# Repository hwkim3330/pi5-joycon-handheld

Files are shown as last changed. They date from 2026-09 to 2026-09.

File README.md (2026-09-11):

# Pi 5 + 5" Touch Display 2 + Joy-Con
## Clear Laser-Cut Acrylic Handheld

**Status: v8 SUBMITTED FOR FABRICATION — PHYSICAL FIT NOT YET VERIFIED.**
Neither the Joy-Con guide nor the display fit has been checked on real parts.
Geometry is validated against the official 5" STEP, the Cuttlephone reference and the
ordered drawing itself (`python3 verify_dxf.py`).

| front | rear (open back) |
|---|---|
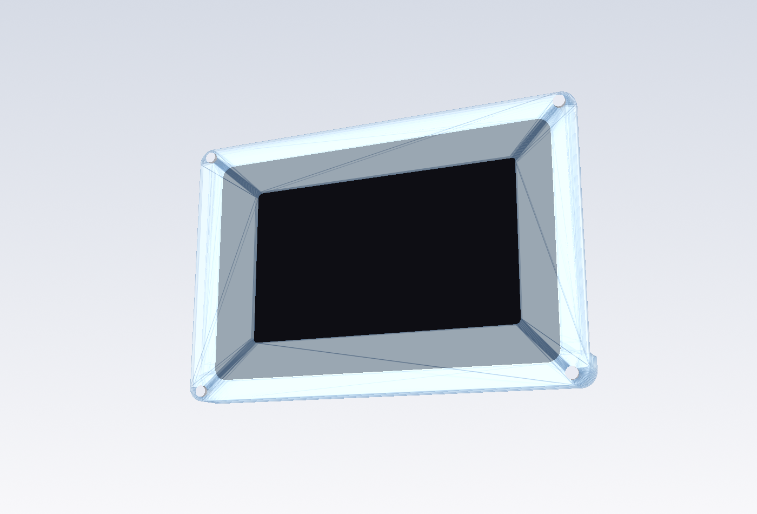
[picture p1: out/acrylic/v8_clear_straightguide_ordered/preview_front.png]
front
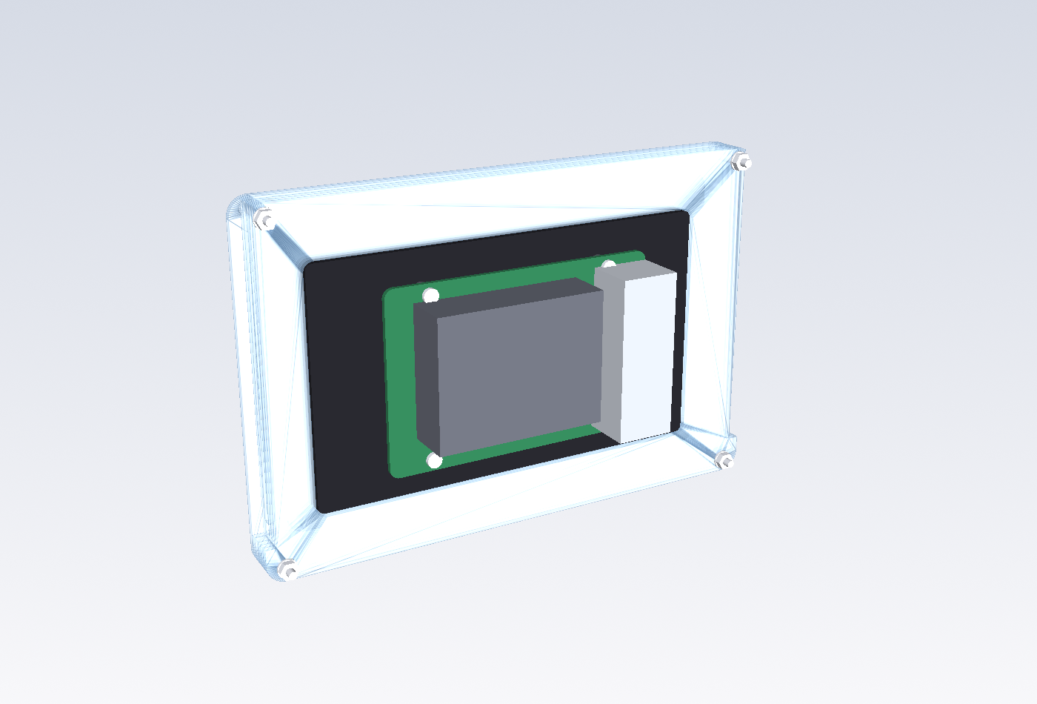
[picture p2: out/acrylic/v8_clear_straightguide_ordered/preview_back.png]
back
|  |  |

| exploded | side guide section |
|---|---|
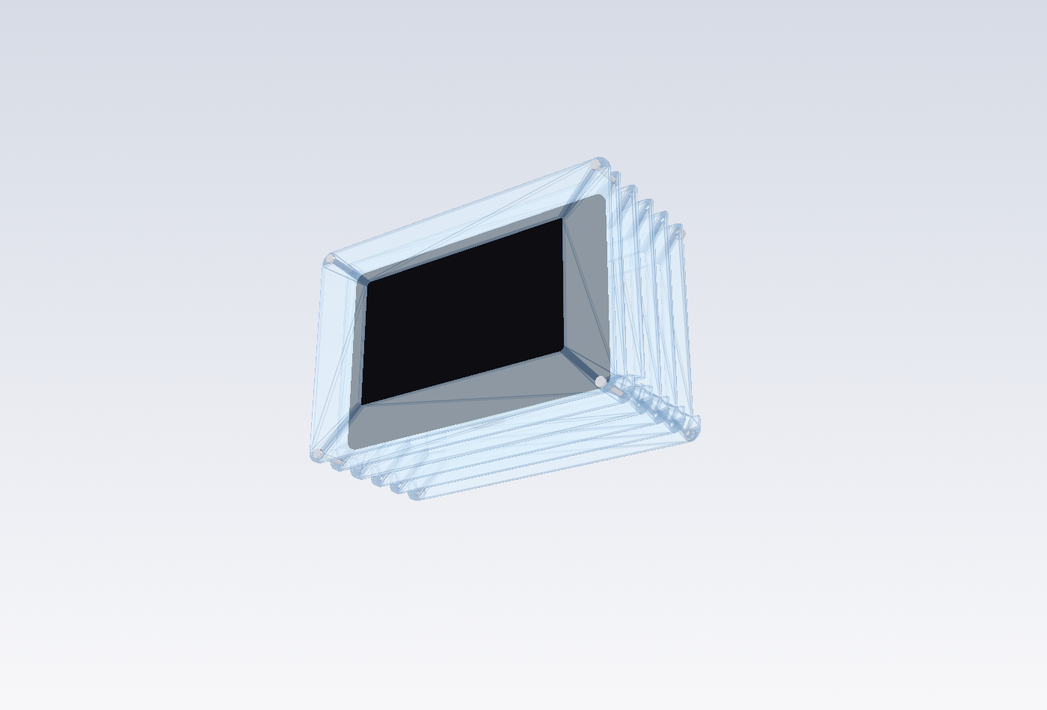
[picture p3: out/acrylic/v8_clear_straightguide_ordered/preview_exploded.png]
exploded
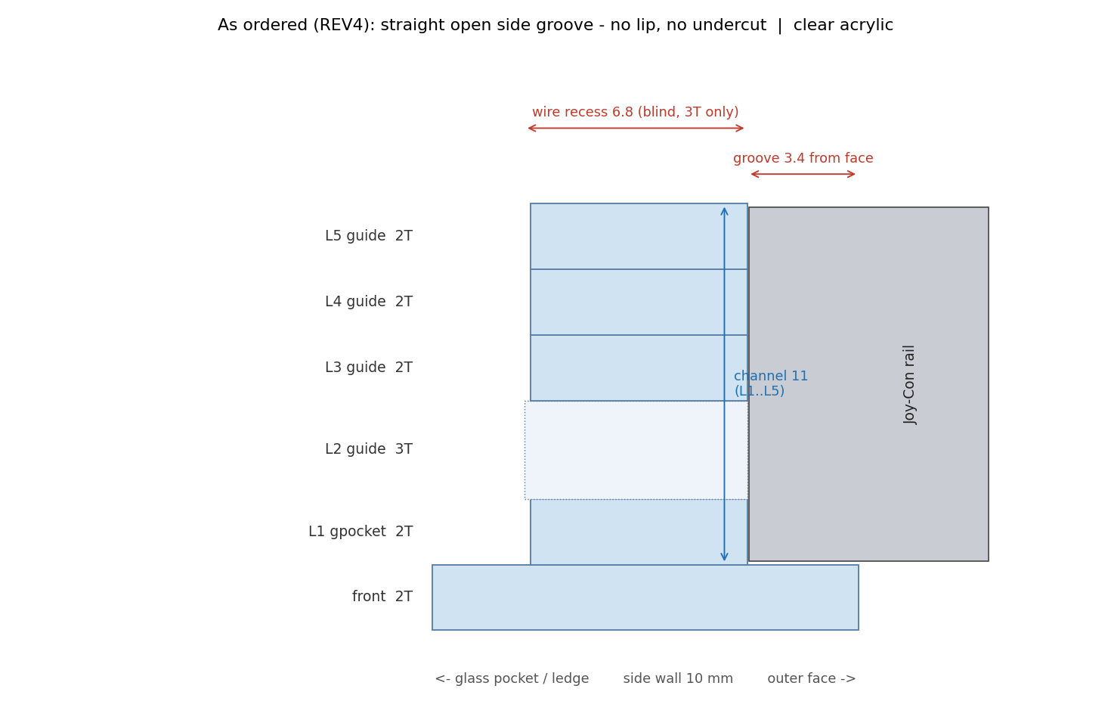
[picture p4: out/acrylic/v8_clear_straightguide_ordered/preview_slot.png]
slot
|  |  |

## What it is
A **13.0 mm** stack of **clear cast acrylic** around the official **Raspberry Pi Touch
Display 2 (5")**, open at the back so the **Raspberry Pi 5**, its Active Cooler / NVMe
HAT and cables stay visible. Real first-generation **Joy-Cons slide into straight open
grooves** cut into the side walls — no 3D printing, no glue. All case fasteners are
**silver M2.5 button-heads** on the front, washer + nut on the rear face.

Body 164.4 × 108.5 mm, 6 acrylic pieces. Source of truth for every number:
`acrylic_panels.py`; `verify_dxf.py` re-measures the exported DXFs against it *and*
against dimensions read off the ordered drawing.

**Interactive assembly guide (3D, click a plate to identify it):
https://hwkim3330.github.io/pi5-joycon-handheld/**

**Build it from [`ASSEMBLY.md`](ASSEMBLY.md); order it from [`ORDER.md`](ORDER.md).**

> **Parts fabricated.** The straight groove locates a Joy-Con but does **not** retain it:
> the mouth is 11.0 mm, the rail head is 10.1 mm, and with no undercut nothing overhangs
> it. That is the accepted cost of dropping the 1 mm lip, not a fabrication error.
> `out/acrylic/v8r_liplayers_recut/` re-cuts **only L1 and L5** with the blind lip pocket
> to restore a real T-slot (mouth 7.0), reusing the front, L2, L3 and L4 you already have.
> See ASSEMBLY.md §6.

## Versions
| version | side guide | layers | total | sheets | status |
|---|---|---|---|---|---|
| **v8_clear_straightguide_ordered** | straight groove 3.4 deep, no lip | 2 / 2 / **3** / 2 / 2 / 2 | **13.0 mm** | 2T · 3T | **ordered / fabricated** |
| v7_clear_exact | T-slot, 1.5T pockets, inner 10.0 | 2 / 1.5 / 5 / 2 / 1.5 / 1.5 | 13.5 mm | 1.5T · 2T · 5T | earlier reference |
| v7_clear_acrylzip | T-slot, 2T pockets, inner 11.0 (+PET liners) | 2 / 2 / 5 / 2 / 2 | 13.0 mm | 2T · 5T | earlier reference |

Every version has a matching fit coupon in `out/acrylic/test_coupon_<version>/`.

## Design history
1. **v7 T-slot** (`v7_clear_exact`, `v7_clear_acrylzip`) — female T-slot with a 1.0 mm
   acrylic lip, built from stacked pocket/mouth layers. Kept as reference; **not** what
   was ordered.
2. **v8 straight guide** — the ordered revision. The T-slot left a 1.0 mm lip running the
   full length of the slot on the pocket layers: laser-cuttable, but a long thin acrylic
   tongue and judged mechanically fragile. It was replaced by a plain straight groove in
   every structural layer, so the side wall keeps full section. The 5T sheet was dropped
   and its depth redistributed as 3T + one more 2T layer, holding the total at 13.0 mm.
   The cost is that a straight groove has no undercut: it guides the Joy-Con but does not
   lock it, so some lateral play is expected and accepted.
3. **Jetson Nano / Orin experiments** — a separate line of work that considered a Jetson
   as the brain instead of a Raspberry Pi. Never part of this repository's design and
   **not part of this order**. Only a stale comment in `legacy/switch_handheld.py`
   survives from it.

## As ordered (v8)
Fabricated from `KETI_Acrylic_Order_REV4_StraightGuide_Transparent_2T_3T.dxf`:
transparent acrylic, **Front 2T + L1 2T + L2 3T + L3 2T + L4 2T + L5 2T = 6 pieces,
13.0 mm**, body ≈ 164.4 × 108.5 mm, open rear, M2.5 through-bolt assembly, no acrylic glue.

* **Side guide** — straight open groove, **3.4 mm** deep, open at the top edge, **91.5 mm**
  of guide with a **6 mm** contact bay below it (97.5 mm of groove, ~11 mm of solid
  acrylic under that). Present in L1–L5; the front plate has no groove and closes the
  front of the 11 mm channel. No 1 mm tongues anywhere.
* **L2 (3T)** keeps a **3.2 × 6.8 mm wire recess** on both sides in the contact-bay
  region, for future charging contacts. As drawn it is **blind** — it stops 5.4 mm short
  of the display cavity, so feeding a wire in from the inside needs an opening that is
  not in the ordered drawing.
* Optional thin clear PET/tape may be added to the groove faces after a physical fit test.

`verify_dxf.py` checks the generated v8 DXFs against dimensions measured from that
drawing: outline, bolt pattern, window size and offset, glass pocket, ledge cavity and
offset, groove floor and bottom, wire recess, and the 2/2/3/2/2/2 thickness list.

## Assembly, front to rear
```
M2.5 button-head → front 2T → Touch Display 2 → L1 2T → L2 3T → L3 2T → L4 2T → L5 2T → washer + nut
```
The display is **not** sandwiched between two flat sheets: its 0.70 mm cover glass is
seated in the **L1 pocket** (144.40 × 92.46), and L2–L5 have a smaller frame-shaped
cavity (126.24 × 74.46, offset x −3.47) so the glass border rests on that ledge while the
rear frame passes through. Full procedure in [`ASSEMBLY.md`](ASSEMBLY.md).

## The display, measured from the official STEP
`reference/td2_5in.step` is Raspberry Pi's own 5" model (RP-009152-DD-1, public on the
Product Information Portal). Read with CadQuery; landscape here = display long axis
along case X, origin at the glass centre.

| feature | mm | in code |
|---|---|---|
| cover glass | 143.40 × 91.46 × **0.70**, corners **R5.0** | `GLASS_*` |
| rear frame (largest rear body) | 124.74 × 72.96, centre **x −3.47** from the glass centre, **9.70** behind the glass back | `FRAME_*` |
| glass + frame envelope in the STEP | **10.40** — what the acrylic pocket is sized to | `STEP_BODY_D` |
| complete product depth (documentation) | **16.0** — includes the rear stand-offs and what mounts on them | `OFFICIAL_DEPTH` |
| active-area (panel) centre | **x −2.47** from the glass centre → bezel 13.5 mm one end, 18.4 the other | `PANEL_DX` → `ACT_DX` |
| four rear M2.5-size bosses | (±51.85, ±25.5) = **103.7 × 51.0** — display assembly features, *not* Pi mounting | `STEP_REAR_BOSSES` |
| Pi mounting stand-offs | **not modelled in the STEP** | — |
| anything outside the frame footprint or behind its rear plane | none | |
| active / viewing area (product brief) | 110.4 × 62.1 / 111.5 × 63.0 | `ACTIVE_*`, `VIEW_*` |

The window is cut to the **viewing** area + 0.25 mm/side = 112.0 × 63.5, centred on the
panel (x −2.47), not on the glass. Active and viewing areas are separate variables.
Official drawings are reference-only: **measure a real display before any volume order**
(the sign of `ACT_DX` flips if you rotate the display the other way).

### How the display is held (like every bezel)
```
front 2T  ────────────────────────   clear, window over the viewing area
L1 1.5T   glass pocket 144.4 × 92.46 : the 0.70 glass sits here, gasket ring behind its border
L2…       ledge cavity 126.24 × 74.46: the glass border rests on this step (≥ 4.6 mm wide)
          the 9.7 mm rear frame passes through; open back
```
Body depth is sized to the STEP's 10.40 mm glass + frame envelope, **not** to the 16 mm
complete-product depth in the documentation — the difference is the rear stand-offs and
the Pi, which deliberately stick out of the open back.
Forward: front plate. Backward: the ledge. Nothing else is needed — the earlier
"rear retaining bars" idea was wrong: at the module's edge there is only 0.7 mm of glass,
no rear surface to press on. The **STEP-modelled glass/frame body** ends 1.1 mm (exact) / 0.6 mm (acrylzip) inside
the case back; the rear stand-offs and the Pi bolted to them project out through the
open back, which is why the complete product is documented as 16 mm deep while the
acrylic body is only 11.5.

### Pi 5 mounting
Per Raspberry Pi's documentation you can mount **any SBC form-factor Raspberry Pi
directly to the back of the Touch Display 2**: align the Pi with the **four corner
stand-offs** on the display rear and secure it with the **four supplied M2.5 screws**.
That is the method assumed here. Cables: 22→15-way FFC, display J1 → Pi GPIO power.

Those four screws hold the Pi to the display. They are **not** the case bolts and have
nothing to do with holding the display in the acrylic.

The STEP models the glass and frame body only — it does **not** model the stand-offs, so
their exact coordinates and height are not published data. The preview therefore draws
the Pi's 58 × 49 pattern centred on the display's rear frame, at a nominal 4 mm
stand-off height; treat that placement as illustration. (An earlier revision of this
repo misread the STEP's four 103.7 × 51.0 rear bosses as the Pi mounting points and
wrongly concluded a bracket was required. Those bosses are display assembly features.
No case geometry was ever derived from them.)

## Joy-Con geometry (v7 reference)
The ordered v8 replaces this T-slot with a plain groove (see *Design history*); the
reference numbers below are why the slot sits where it does, and still set the guide
length, contact bay and groove depth in v8.

Nintendo puts the **female slot on the console** and the **male rail on the Joy-Con**.
Reference geometry is derived from the field-tested
[Cuttlephone](https://github.com/SiloCityLabs/Cuttlephone) design (`phone_case.scad`):
mouth 7.1, inner 10.1, cavity 2.4, lock notch 3.8 wide 9.4 from the top, rail 91.5.
Laser kerf and actual sheet thickness still require a physical fit test.

In v7 this was built from the layer stack as a T profile (mouth 5T + 2T = 7.0, inner
7.0 + 2 × pocket, lip 1.0). **v8 drops the lip entirely** and cuts one plain 3.4 mm
groove per layer instead; what carries over is the extent — open at the top edge, Joy-Con
seated 91.5 mm below it, 6 mm contact bay under that for a Joy-Con charging-rail part
(pin 4 = 5 V, pins 1–2 = GND).

## Bezel (cosmetic, optional)
The front is clear, so the display's black bezel shows through it — that is the design.
To hide it, put black vinyl / masking film on the **back** of the front plate, leaving the
112.0 × 63.5 window open. No extra sheet.

## Kerf
DXF geometry is nominal finished geometry; the shop applies cutter compensation; do not
add your own offset. Slot widths come from sheet thickness, hence the coupon.

## Still to verify on hardware
1. **Joy-Con fit in the straight guide** — how much lateral play there actually is, and
   whether a PET/tape liner is wanted. Nothing has been tried on real parts.
2. Real glass/frame dimensions vs the STEP on your unit (reference-only drawings).
3. Stand-off positions and height on a real display (not in the STEP), and that the
   Pi + Active Cooler clear the case back as drawn.

## Files
```
acrylic_panels.py    all geometry + design checks (raises before exporting on failure)
verify_dxf.py        re-measures the exported DXFs against the code
render_previews.py   preview PNGs (VTK) + slot section (matplotlib)
ORDER.md             what to order, per version, plus hardware BOM
ASSEMBLY.md          build order and procedure for the as-ordered v8
make_site.py         builds docs/ - the GitHub Pages 3D assembly viewer
docs/                the published page (index.html + plates.json)
reference/measure_step.py  re-measures the official 5" STEP -> every display number here
reference/README.md        how to download td2_5in.step (5.2 MB, deliberately not committed)
out/acrylic/v8_clear_straightguide_ordered/  AS ORDERED - DXFs, sheet_*.dxf, manifest.txt, previews, STL
out/acrylic/v8r_liplayers_recut/   retrofit: 2 replacement plates (L1r, L5r) that add the missing undercut
out/acrylic/v7_clear_exact/        earlier T-slot reference
out/acrylic/v7_clear_acrylzip/     earlier T-slot reference, standard thicknesses
out/acrylic/test_coupon_ordered/   fit coupon for the ordered guide
out/acrylic/test_coupon_exact/     fit coupon, v7
out/acrylic/test_coupon_acrylzip/  fit coupon, v7
legacy/                            earlier drafts — NOT FOR FABRICATION
```
`pip install cadquery ezdxf`, then `python3 acrylic_panels.py && python3 verify_dxf.py && python3 render_previews.py`.

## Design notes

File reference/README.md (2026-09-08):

# reference — official Raspberry Pi 5" Touch Display 2 model

`td2_5in.step` is **not committed** (5.2 MB binary). Fetch it, then re-run the
measurement to reproduce every display number in `acrylic_panels.py`:

```bash
curl -L -o reference/td2_5in.step \
 'https://pip-assets.raspberrypi.com/categories/1083-raspberry-pi-touch-display-2/documents/RP-009152-DD-1-raspberry-pi-touch-display-2-step-5inch.step'
python3 reference/measure_step.py
```
(Product Information Portal → Raspberry Pi Touch Display 2 → *raspberry-pi-touch-display-2-step-5inch*, RP-009152-DD-1, no login.)

## Measured 2026-09-08 — what the design uses
Portrait STEP coordinates, origin as authored; **+Z is the front**.

| feature | value |
|---|---|
| cover glass | 91.46 × 143.40 × **0.70**, corner **R5.0** (8 circular edges), centre (0, +2.47) |
| rear frame (largest rear body) | 72.96 × 124.74 × 7.00, centre (0, −1.00), z[−5.48, +1.52] |
| active panel body | 71.16 × 120.94 × 2.57, centre (0, 0) |
| frame centre vs glass centre | **−3.47** along the long axis |
| panel centre vs glass centre | **−2.47** along the long axis |
| total depth (glass front → rearmost) | **10.40** (4.92 → −5.48) |
| four rear M2.5-size bosses | 4 × (±25.50, −49.38 / +54.32) → pitch **51.00 × 103.70**; boss r1.75, hole r1.25, z[−5.48, −1.98]. Display assembly, *not* Pi mounting |
| FFC connector block | 21.00 × 8.90 × 2.70 at (0.03, +37.37) |
| J1 power connector block | 16.40 × 5.20 × 2.00 at (+4.13, −30.19) |
| outside the frame footprint | none |
| behind the frame rear plane | none |

Two consequences the documentation does not spell out:

1. **The STEP models the glass + frame body only: a 10.40 mm envelope.** The
   documented depth of the complete product is **16 mm** — the difference is the rear
   mounting stand-offs and whatever is bolted to them. The acrylic pocket is sized to
   10.40; the stand-offs and the Pi pass through the open back.
2. **The stand-offs are not in the STEP.** Its four rear M2.5-size bosses are
   103.70 × 51.00 apart, which is no Pi hole pattern, so they are display assembly
   features. Per Raspberry Pi's documentation an SBC-form-factor Pi mounts directly to
   the display's four corner stand-offs with the four supplied M2.5 screws. Do not
   derive case geometry from the 103.70 × 51.00 bosses (this repo does not).

Official drawings are reference-only. Measure a real display before a volume order.

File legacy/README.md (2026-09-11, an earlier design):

# legacy — NOT FOR FABRICATION

Earlier drafts kept for reference only.

* `joycon_rail.py` — modelled a MALE dovetail on the case. Backwards: on a Switch the
  console has the female T-slot and the Joy-Con carries the male rail.
* `switch_handheld.py` — an all-3D-printed shell with the same wrong rail.

`switch_handheld.py` still carries Jetson-era comments from a separate line of
experiments (Jetson Nano / Orin Nano as the brain). Those experiments were never part of
this repository's design and were **not** part of the acrylic order — see the design
history in the main README.

The current design is `../acrylic_panels.py`.

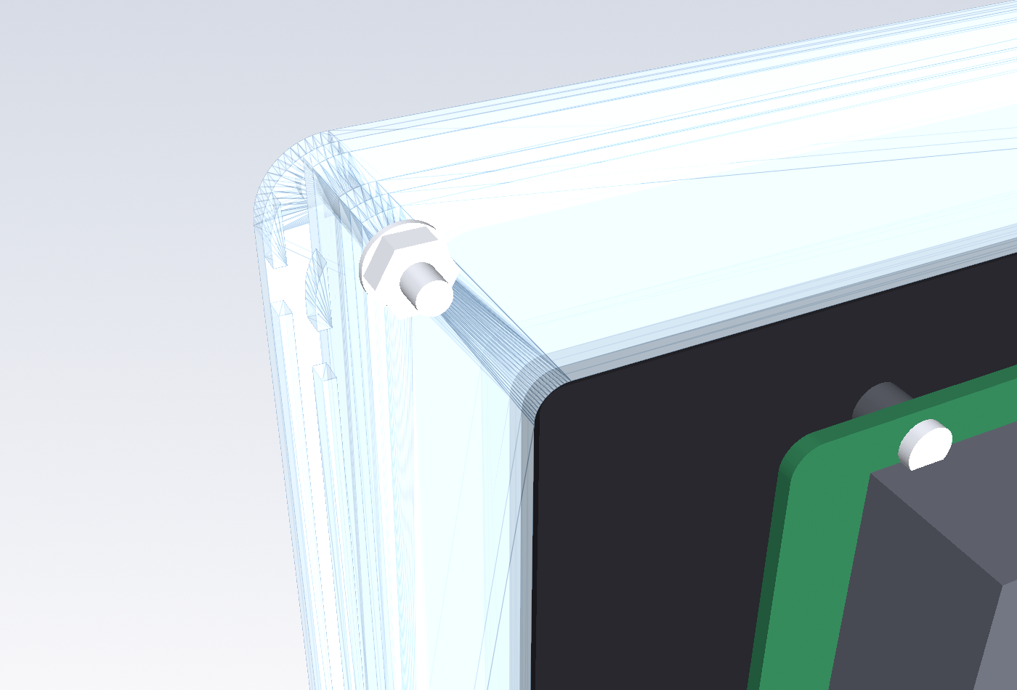
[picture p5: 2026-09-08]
out/acrylic/v7_clear_acrylzip/preview_ledge.png

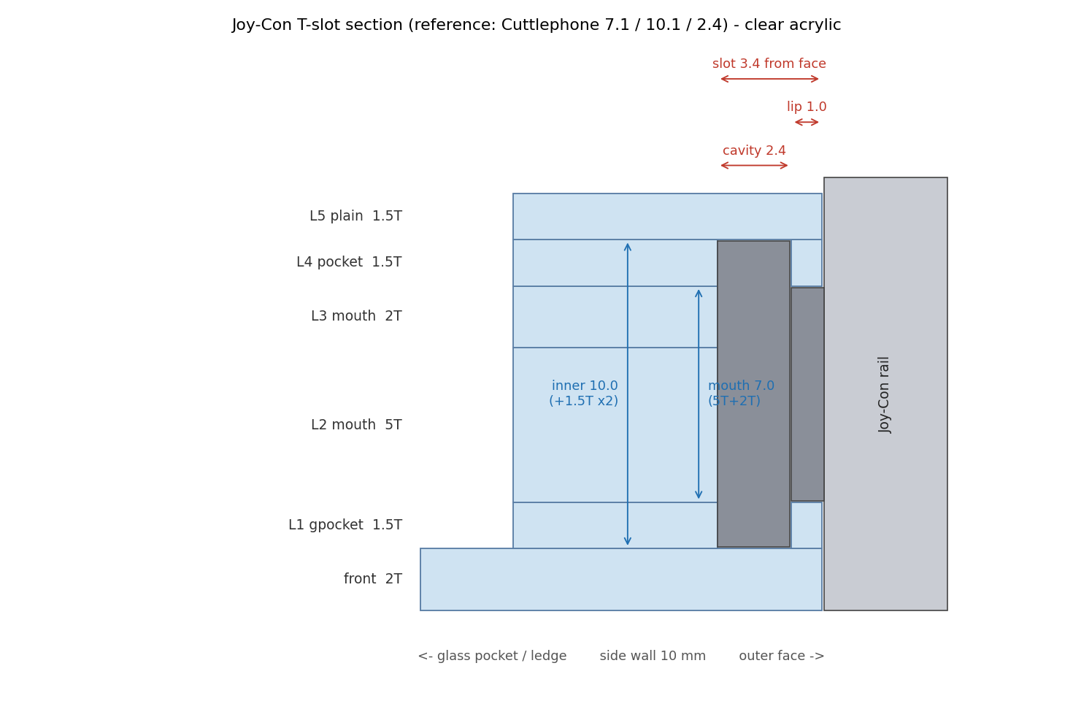
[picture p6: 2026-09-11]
out/acrylic/v7_clear_exact/preview_slot.png

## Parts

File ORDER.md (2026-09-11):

# ORDER — clear cast acrylic + silver hardware

Everything is **clear (transparent) CAST acrylic**. No black, no smoked. All case
hardware is **silver / stainless M2.5**. Hand the shop `out/acrylic/<version>/sheet_<thickness>.dxf`
— one DXF per thickness.

> **What was actually ordered is v8 (below).** v7 is kept as the earlier reference design.
>
> **Cut a fit coupon first.** Each version has one in `out/acrylic/test_coupon_<version>/`:
> a 40 mm section of the side guide with the identical layer order and geometry, two M2.5
> clamp bolts, slide a Joy-Con in from the open end. The guide has never been cut in
> acrylic — for the ordered v8 the coupon is `test_coupon_ordered` (5 pieces, 2T + 3T).

## v8_clear_straightguide_ordered — AS ORDERED / AS FABRICATED

Submitted as `KETI_Acrylic_Order_REV4_StraightGuide_Transparent_2T_3T.dxf`.
**Fabrication submitted; physical fit not yet verified.**

| part | thickness | qty | material | color | notes |
|---|---|---|---|---|---|
| front | 2T | 1 | cast acrylic | **clear** | window 112.0 × 63.5 at x −2.47; no groove |
| L1 | 2T | 1 | cast acrylic | clear | glass pocket 144.40 × 92.46; straight groove |
| L2 | **3T** | 1 | cast acrylic | clear | ledge cavity; groove; 3.2 × 6.8 blind wire recess both sides |
| L3 | 2T | 1 | cast acrylic | clear | ledge cavity; straight groove |
| L4 | 2T | 1 | cast acrylic | clear | ledge cavity; straight groove |
| L5 | 2T | 1 | cast acrylic | clear | ledge cavity; straight groove |

**6 acrylic pieces, 13.0 mm total, body 164.4 × 108.5 mm, open rear, no glue.**
Sheets: `sheet_2T.dxf` (front, L1, L3, L4, L5) and `sheet_3T.dxf` (L2).

Side guide: plain straight groove **3.4 mm** deep, open at the top edge, **91.5 mm** guide
+ **6 mm** contact bay. No T-lip. Lateral play is accepted; thin clear PET/tape may be
added after a fit test.

Hardware: **4 × M2.5 × 18** silver button-head (17.0 mm needed; ×20 with nyloc),
4 × M2.5 washer, 4 × M2.5 nut. Plus the gasket strip listed in the BOM below.

> The same fabrication sheet also carried a separate project — 20 × LAN9692 frame plates
> (A/B/C/D, 3T, 5 each, 250 × 180 mm). Nothing to do with this case.

## The two earlier v7 reference versions
| | v7_clear_exact | v7_clear_acrylzip |
|---|---|---|
| Joy-Con pocket layers (L1, L4) | **1.5T** | **2T** |
| raw Joy-Con inner width | 10.0 mm (reference 10.1) | 11.0 mm |
| liners | none | 0.45 mm clear PET on each pocket face → ~10.1 |
| body / total acrylic thickness | 11.5 / **13.5 mm** | 11.0 / **13.0 mm** |
| sheets | 1.5T · 2T · 5T | 2T · 5T |
| use when | the shop can supply 1.5T clear cast | standard-thickness auto-quote (Acrylzip 아크리애) |

These were the T-slot designs that preceded the ordered revision. If 1.5T clear cast is available, **exact** is the closer of the two to the reference geometry. The acrylzip version is the
standard-thickness fallback; its 11.0 mm inner width is not "close enough" on its
own — fit the liners.

## v7_clear_exact — parts (6 acrylic pieces)
| part | thickness | qty | material | color | notes |
|---|---|---|---|---|---|
| front | 2T | 1 | cast acrylic | clear | window 112.0 × 63.5 at x −2.47 (viewing area + 0.25/side), 4 × Ø2.8 |
| L1_gpocket | **1.5T** | 1 | cast acrylic | clear | glass pocket 144.40 × 92.46 R5.5 **+** Joy-Con slot pocket + lock notch |
| L2_mouth | 5T | 1 | cast acrylic | clear | frame-size ledge cavity 126.24 × 74.46 (x −3.47) + slot mouth + 3.2 wire slot |
| L3_mouth | 2T | 1 | cast acrylic | clear | ledge cavity + slot mouth |
| L4_pocket | **1.5T** | 1 | cast acrylic | clear | ledge cavity + slot pocket + lock notch |
| L5_plain | 1.5T | 1 | cast acrylic | clear | ledge cavity; the STEP glass/frame body ends 1.1 mm inside the case back |

Sheets: `sheet_1.5T.dxf` (L1, L4, L5), `sheet_2T.dxf` (front, L3), `sheet_5T.dxf` (L2).

## v7_clear_acrylzip — parts (5 acrylic pieces)
| part | thickness | qty | material | color | notes |
|---|---|---|---|---|---|
| front | 2T | 1 | cast acrylic | clear | as above |
| L1_gpocket | **2T** | 1 | cast acrylic | clear | glass pocket + slot pocket; liner on the slot face |
| L2_mouth | 5T | 1 | cast acrylic | clear | ledge + mouth + wire slot |
| L3_mouth | 2T | 1 | cast acrylic | clear | ledge + mouth |
| L4_pocket | **2T** | 1 | cast acrylic | clear | ledge + slot pocket; liner on the slot face. STEP glass/frame body ends 0.6 mm inside |

Sheets: `sheet_2T.dxf` (front, L1, L3, L4), `sheet_5T.dxf` (L2).

## Fit coupons (cut these first)
| folder | pieces | thicknesses |
|---|---|---|
| **`test_coupon_ordered`** | **5** — C1 2T, C2 3T, C3 2T, C4 2T, C5 2T | **2T, 3T** (matches the ordered build) |
| `test_coupon_exact` | **5** — C1 1.5T, C2 5T, C3 2T, C4 1.5T, C5 1.5T | 1.5T, 2T, 5T |
| `test_coupon_acrylzip` | **4** — C1 2T, C2 5T, C3 2T, C4 2T | 2T, 5T |

16 × 40 mm each, slot open at the top, 6 mm stop at the bottom, two Ø2.8 clamp holes.
Clamp with 2 × M2.5 × 20 + nuts.

## Hardware BOM (case) — separate from the display's own screws
| item | qty | spec | note |
|---|---|---|---|
| button-head screw | 4 | **M2.5 × 18**, silver / A2 stainless | computed: v8/acrylzip stack 13.0 + washer 0.5 + nut 2.0 + 1.5 stick-out = 17.0 → 18 (v7 exact 17.5 → 18). Nyloc (≈3.0): **M2.5 × 20** |
| washer | 4 | M2.5, stainless | under the nut, on the rear face of the last layer |
| nut | 4 | M2.5 hex or nyloc, stainless | |
| glass gasket | 1 ring | soft foam or silicone tape, 4 mm wide, **1.0 mm** uncompressed (v8 and v7 exact; 1.5 mm for v7 acrylzip) | on the ledge behind the glass border; takes up the pocket depth beyond the 0.70 glass, keeps the glass pressed to the front plate |
| clear PET liner | 4 | 0.45 mm × ~3 × 90 mm | **v7 acrylzip only** (for v8, add liner/tape only after a fit test); 0.5 mm PET gives 10.0 — decide on the coupon |
| Joy-Con charging rail part | 2 | L + R | optional; 6 mm pocket below the seat, 5 V/GND via the wire slot (pin 4 = 5 V, pins 1–2 = GND, small buck) |

**Not in this BOM:** the four M2.5 screws in the Touch Display 2 box. Those mount the
Raspberry Pi directly to the display's four rear corner stand-offs (the official
method); they have nothing to do with this case.

## Notes for the shop
* **Clear cast acrylic** (캐스트 투명), not extruded.
* DXF is **nominal finished geometry**. Apply your normal cutter compensation, do
  **not** add kerf on top. Ø2.8 holes are already M2.5 clearance.
* v8: the side guide is a plain 3.4 mm groove, so its depth comes from the cut and its
  width from the sheet stack (11.0 mm of L1–L5). No thin acrylic tongues anywhere.
* v7 only: mouth (7.0) and inner width come from sheet thickness; L1/L4 carry a 1.0 mm
  lip along the slot and must be handled gently until bolted. That fragility is exactly
  why v8 exists.

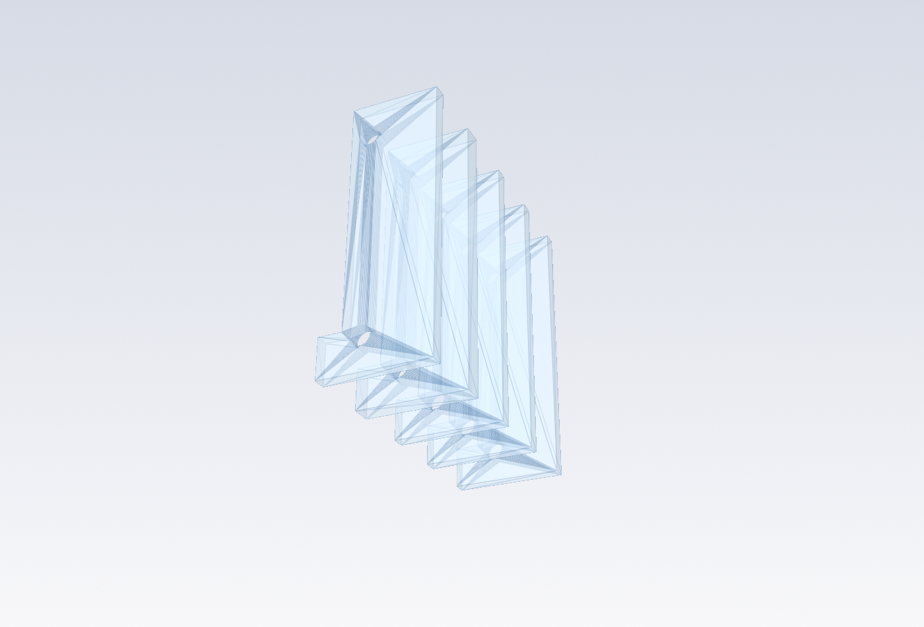
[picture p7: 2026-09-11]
out/acrylic/test_coupon_ordered/preview_exploded.png

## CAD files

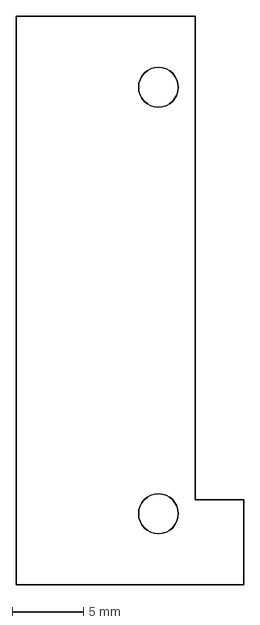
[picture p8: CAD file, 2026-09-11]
out/acrylic/test_coupon_acrylzip/C3_mouth_2T.dxf
16.0 x 40.0 mm

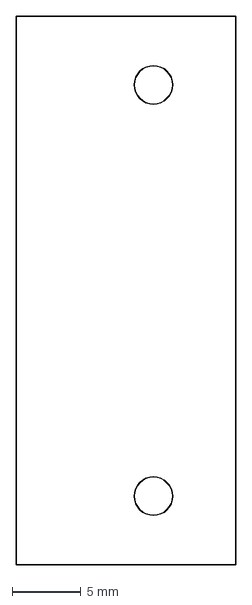
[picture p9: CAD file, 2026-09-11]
out/acrylic/test_coupon_exact/C5_plain_1.5T.dxf
16.0 x 40.0 mm

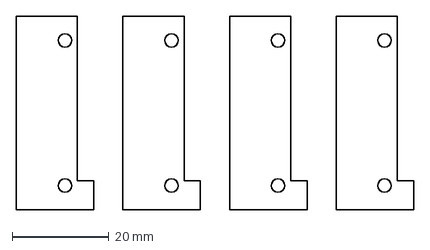
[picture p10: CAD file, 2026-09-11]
out/acrylic/test_coupon_ordered/sheet_2T.dxf
82.0 x 40.0 mm

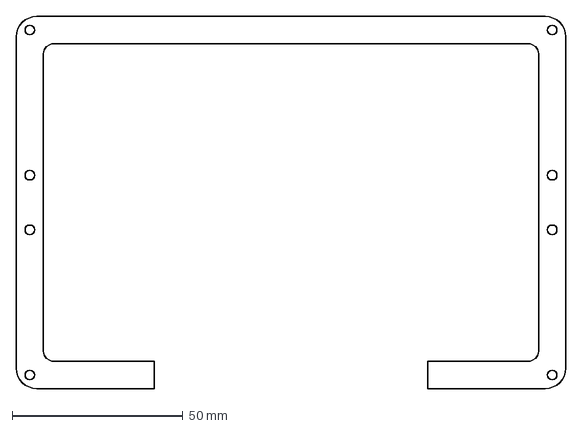
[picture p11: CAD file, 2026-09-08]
out/acrylic/v4_open_back/L5_pi_5T.dxf
161.0 x 109.0 mm

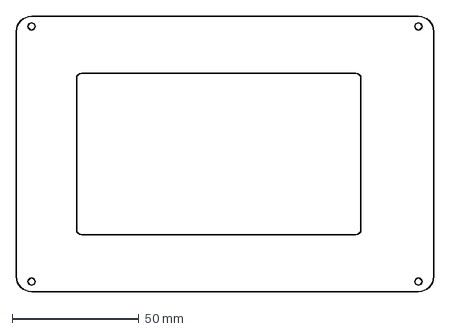
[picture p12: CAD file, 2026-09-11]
out/acrylic/v7_clear_acrylzip/front_2T.dxf
164.4 x 108.5 mm

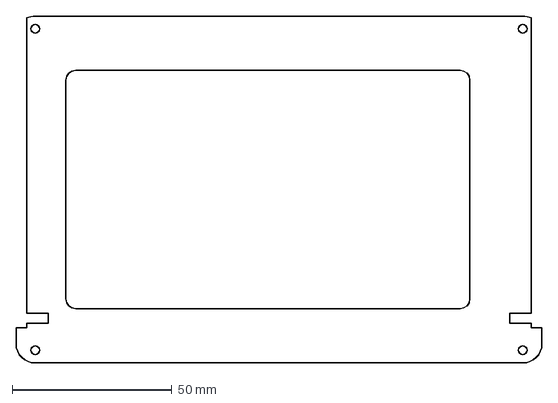
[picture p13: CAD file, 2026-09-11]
out/acrylic/v7_clear_exact/sheet_5T.dxf
164.4 x 108.5 mm

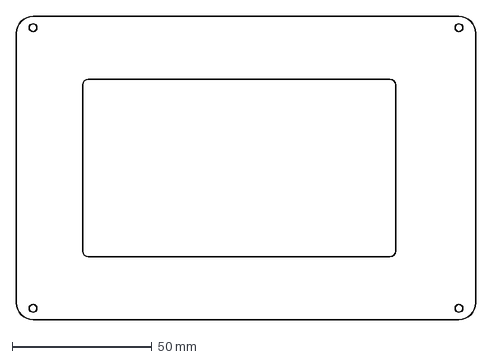
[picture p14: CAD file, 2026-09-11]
out/acrylic/v8_clear_straightguide_ordered/front_2T.dxf
164.4 x 108.5 mm

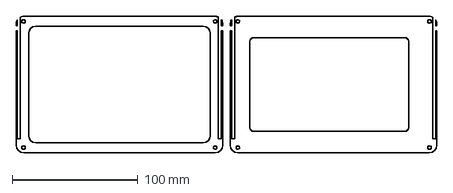
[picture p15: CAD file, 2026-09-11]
out/acrylic/v8r_liplayers_recut/sheet_2T.dxf
334.8 x 108.5 mm

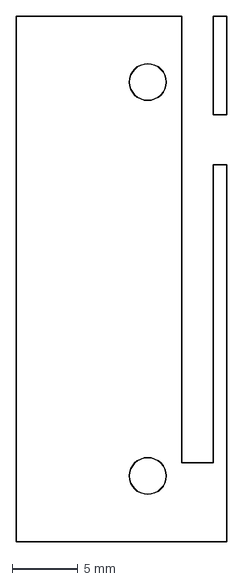
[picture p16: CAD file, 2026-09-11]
out/acrylic/test_coupon_acrylzip/C1_gpocket_2T.dxf
16.0 x 40.0 mm

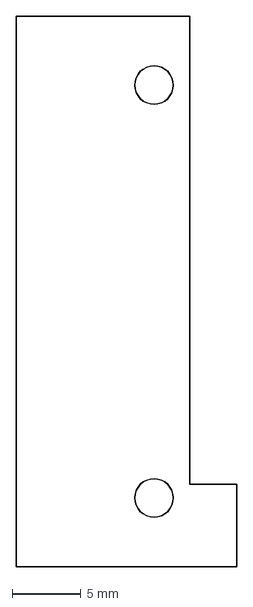
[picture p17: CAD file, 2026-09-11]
out/acrylic/test_coupon_exact/sheet_5T.dxf
16.0 x 40.0 mm

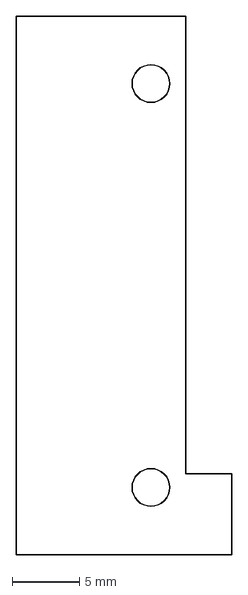
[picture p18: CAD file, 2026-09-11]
out/acrylic/test_coupon_ordered/C1_gpocket_2T.dxf
16.0 x 40.0 mm

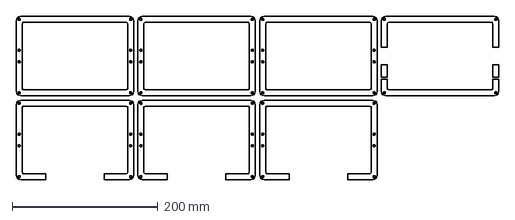
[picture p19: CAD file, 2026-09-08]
out/acrylic/v4_open_back/sheet_5T.dxf
662.0 x 224.0 mm

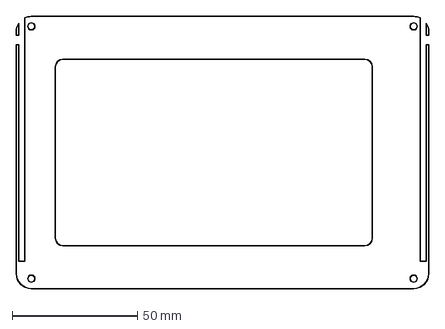
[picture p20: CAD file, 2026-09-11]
out/acrylic/v7_clear_acrylzip/L4_pocket_2T.dxf
164.4 x 108.5 mm

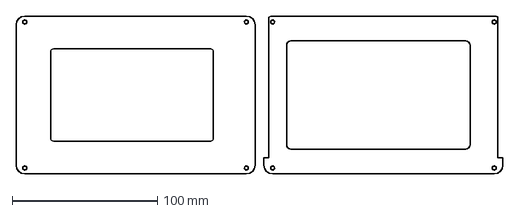
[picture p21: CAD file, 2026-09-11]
out/acrylic/v7_clear_exact/sheet_2T.dxf
334.8 x 108.5 mm

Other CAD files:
out/acrylic/v8_clear_straightguide_ordered/sheet_2T.dxf
out/acrylic/v8r_liplayers_recut/L5r_pocket_lip_2T.dxf
out/acrylic/test_coupon_acrylzip/C4_pocket_2T.dxf
out/acrylic/test_coupon_exact/sheet_1.5T.dxf
out/acrylic/test_coupon_acrylzip/C2_mouth_5T.dxf
out/acrylic/test_coupon_acrylzip/sheet_2T.dxf
out/acrylic/test_coupon_acrylzip/sheet_5T.dxf
out/acrylic/test_coupon_acrylzip/stack_preview.stl
out/acrylic/test_coupon_exact/C1_gpocket_1.5T.dxf
out/acrylic/test_coupon_exact/C2_mouth_5T.dxf
out/acrylic/test_coupon_exact/C3_mouth_2T.dxf
out/acrylic/test_coupon_exact/C4_pocket_1.5T.dxf
out/acrylic/test_coupon_exact/sheet_2T.dxf
out/acrylic/test_coupon_exact/stack_preview.stl
out/acrylic/test_coupon_ordered/C2_guide_3T.dxf
out/acrylic/test_coupon_ordered/C3_guide_2T.dxf
out/acrylic/test_coupon_ordered/C4_guide_2T.dxf
out/acrylic/test_coupon_ordered/C5_guide_2T.dxf
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

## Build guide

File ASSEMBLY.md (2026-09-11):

# Assembly — the parts you have

For the fabricated build, `KETI_Acrylic_Order_REV4_StraightGuide_Transparent_2T_3T.dxf`
= `out/acrylic/v8_clear_straightguide_ordered/`.

**Interactive 3D version of this guide — rotate the stack, click a plate to see which one
it is: https://hwkim3330.github.io/pi5-joycon-handheld/**

**Read the Joy-Con section first.** The case assembles and works, but the side guide as
built does **not** lock a Joy-Con on. That is a consequence of the straight-groove
revision, not a fabrication error.

---

## 1. Check what came back

Six clear plates. Identify them by their cutouts, not by guesswork:

| plate | thickness | how to recognise it |
|---|---|---|
| **front** | 2T | one big window (112.0 × 63.5), **no groove** on the side edges |
| **L1** | 2T | large pocket 144.4 × 92.46 (nearly full width) + side grooves |
| **L2** | **3T** | the only 3 mm plate; smaller cavity + a small notch inside each groove |
| **L3 / L4 / L5** | 2T | identical: smaller cavity 126.24 × 74.46 + side grooves |

L3, L4 and L5 are the same part — order among them does not matter.
The smaller cavity is **offset 3.47 mm** toward one end; all of L2–L5 must face the same
way. Stack them and check the cavity edges line up before you bolt anything.

Also needed: 4 × **M2.5 × 18** button-head + 4 washers + 4 nuts (×20 if nyloc), and a
soft gasket strip — thin foam tape or 1 mm silicone, ~4 mm wide, about 480 mm of it.

## 2. Dry-fit
1. Peel the protective film off **both** faces of all six plates.
2. Stack L5 → L1 (no front plate, no display), push the four bolts through.
3. Look down the sides: the grooves in L1–L5 must form one clean straight channel,
   11 mm wide. If one plate is flipped the cavity offset will be obvious.
4. Drop a Joy-Con into a groove from the top and slide it down. It should run freely and
   stop 91.5 mm down. Note how it feels — you will decide about liners later.
5. Take it apart again.

## 3. The display
The glass is **not** sandwiched between flat sheets. L1 is a pocket; the glass sits in it.

1. Lay the gasket strip on the front face of **L2**, as a ring around the cavity, roughly
   over where the glass border will land. It fills the 1.3 mm between the back of the
   glass and L2, so the glass is pressed against the front plate instead of rattling.
2. Put L1 on top of L2.
3. Drop the **Touch Display 2** into the L1 pocket, glass toward the front. Its rear frame
   passes through the cavities in L2–L5; the glass border rests on the ledge.
4. Put the front plate on. Check the window sits over the picture — it is deliberately
   **2.47 mm off centre** because the panel is, so a perfectly centred window would be wrong.

## 4. Bolt it
Front plate → L1 → L2 → L3 → L4 → L5, bolts from the **front**, washer and nut at the
**back**.

Tighten in a cross pattern, **snug only**. Acrylic has no give: if the plate creaks, you
have already gone too far. There is no glue anywhere in this design — the four bolts are
the whole structure.

## 5. Raspberry Pi 5
1. Align the Pi with the **four corner stand-offs on the back of the display** and fix it
   with the **four M2.5 screws that came in the display box**. Those are Raspberry Pi's
   own screws for exactly this, and they are a different set from the case bolts.
2. 22→15-way FFC between display and Pi; J1 on the display → Pi GPIO pins 2 and 6 for power.
3. The Pi, its Active Cooler / NVMe HAT and all cables live outside the open rear. Nothing
   in the acrylic holds them.

---

## 6. Joy-Con — read this

**As built the Joy-Con drops into the groove and slides down, but nothing holds it on.**

The numbers: a first-gen Joy-Con's rail is a T — a head about **10.1 mm wide × 2.4 deep**
behind a neck about **7.1 wide × 0.7 deep**, ~3.1 mm of total protrusion. The ordered
groove is a plain rectangle **11.0 mm wide × 3.4 deep**, the same depth in every layer.

* head 10.1 ≤ channel 11.0 → it goes in ✔
* protrusion 3.1 ≤ depth 3.4 → deep enough ✔
* mouth 11.0 is **wider** than the head 10.1 → nothing overhangs it ✘

So it locates and aligns, and gravity keeps it down in the groove, but pull the Joy-Con
away from the case — which is what your hand does when you hold the thing as a handheld —
and it comes straight off. The straight groove was chosen on purpose to get rid of the
1 mm lip; retention was the price. It is working as drawn.

### What you can do, cheapest first

**a) Leave it. Use the Joy-Cons wirelessly.**
First-gen Joy-Cons pair over Bluetooth; the groove carries no power and no data, so it
was only ever going to *hold* them. Set the unit down or dock it and the grooves position
the Joy-Cons nicely. This costs nothing and nothing is wrong with it — it is just not a
hold-in-your-hands handheld.

**b) Tape lip — chosen method.** Free, ten minutes, and it is enough for a Joy-Con that
only has to stay put rather than take hand load.

Run clear tape along the **front edge** and the **rear edge** of each groove so exactly
**2.0 mm** overhangs the opening from each side. That takes the mouth from 11.0 mm down to
about **7.1 mm**, and the rail head is **10.1 mm** — so it can no longer come out
sideways, while the 7.1 mm neck still passes.

* **Where it sticks.** Front: the front plate's side face is a solid 2 mm band with no
  groove — tape there and let 2.0 mm hang back over the slot. Rear: tape on the back face
  of L5 and let 2.0 mm hang forward. Wrapping each strip around the edge onto the front
  (or rear) face roughly triples the bond area and stops it lifting.
* **Length** ≈ 100 mm, to cover the 97.5 mm of groove.
* **Never tape the groove floor.** There is only 0.3 mm of depth to spare over the
  Joy-Con's 3.1 mm rail; tape on the floor and it will not seat.
* **Tape type**: thin clear PET/polyester or ordinary clear packing tape, **0.1 mm or
  thinner**. No fabric or duct tape — too thick, and it will look terrible on clear acrylic.
* The tape sits at the surface and the head's shoulder is 0.7 mm in, so expect ~0.6 mm of
  wobble before it catches. That is normal and it still holds.

Re-stick it when it lifts. If it keeps peeling or you want to hold the unit by the
Joy-Cons, go to (c).

**c) Re-cut two plates — the actual fix.**
`out/acrylic/v8r_liplayers_recut/` has exactly two replacement plates, **L1r** and **L5r**.
They are the same outline, the same holes, the same cavities, but their side groove is a
**blind pocket** (1.0 mm of material left at the outer face, 2.4 mm cavity behind it)
instead of an open 3.4 mm slot. Put them in place of L1 and L5 and the stack becomes a
real T-slot again:

```
front 2T | L1r 2T lip | L2 3T | L3 2T | L4 2T | L5r 2T lip
mouth = L2+L3+L4 = 7.0     inner = 11.0     (reference 7.1 / 10.1)
```

**Keep the front plate, L2, L3 and L4 you already have.** Same 13.0 mm, same four
M2.5 × 18 bolts, same assembly order. Only two small plates to buy.

> Cut those two in **clear polycarbonate or PETG, not acrylic**. Each carries a 1.0 mm ×
> 97 mm lip along the groove, attached only at its lower end — precisely the thin rib the
> straight-guide revision was meant to avoid. In 2 mm acrylic it is brittle; in PC or PETG
> it flexes instead of snapping. If your shop will only do acrylic, expect to treat those
> two plates as consumables.

Fore-aft play will still be 0.9 mm (inner 11.0 vs 10.1). If it rattles, line the pocket
faces with 0.45 mm clear PET — add it a layer at a time and re-check.

**d) Nothing else is worth doing.** Gluing lips onto the finished parts has nowhere solid
to bond: along the side face only the 2 mm front plate is unbroken, everything behind it
is open groove.

---

## Before you power it up
* Display square in the pocket, window over the picture, no gap at the front.
* Pi's underside and its connectors clear the rear face of L5.
* Bolts snug, no creaking, no stress marks radiating from the holes.
* Decide on Joy-Con retention from section 6 — do the tape test first.

**Status: nothing in this document has been verified on the real parts.** The fit of the
display and of the Joy-Cons is still unknown; the numbers above come from the fabrication
drawing and the official display model, not from measurement of a built unit.

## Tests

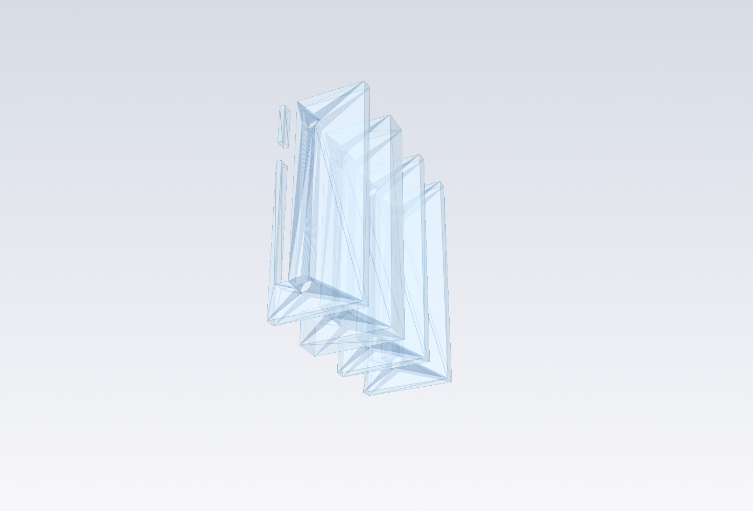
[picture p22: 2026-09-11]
out/acrylic/test_coupon_acrylzip/preview_exploded.png

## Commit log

2026-09-08 Pi 5 + 5in Touch Display 2 + Joy-Con handheld: laser-cut acrylic sandwich (5 versions) and printed dovetail rail modules
    [L1_nuttrap_5T.dxf, L1_plain_5T.dxf, L2_display_5T.dxf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]
2026-09-08 preview: model the display block behind the window, correct front/back camera labels
    [L1_nuttrap_5T.dxf, L1_plain_5T.dxf, L2_display_5T.dxf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]
2026-09-08 v6: LCD-only open-back frame with all-acrylic T-dovetail Joy-Con rails (3T neck tab + glued 2T head strips); drop v4
    [L1_nuttrap_5T.dxf, L1_plain_5T.dxf, L2_display_5T.dxf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]
2026-09-08 Joy-Con slot done right: console side is the FEMALE T-slot (Cuttlephone-measured 7.1/10.1/2.4, notch 3.8@9.4, seat 91.5); cut as per-layer 1.5T/5T/2T/1.5T pockets, open top. Drop printed male rail ve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
    [L10_pi_5T.dxf, L11_pi_5T.dxf, L1_nuttrap_3T.dxf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]
2026-09-08 previews: sectioned T-slot profile view, raking-light front
    [section_preview.stl]
2026-09-08 previews: dimensioned T-slot section diagram, two-material front/back renders
2026-09-08 Clear acrylic v7: rebuild the case from the official 5" STEP, drop the wrong display numbers
    Design is now 100% clear cast acrylic with silver M2.5 hardware, open back, and
    female Joy-Con T-slots; the printed-rail drafts move to legacy/.
    Errors found and fixed:
    * Display depth was 16.0 in the code; the official 5" STEP measures 10.40 mm
    glass-front to rearmost. The body is now sized to the real module.
    * The rear frame is 3.47 mm off the glass centre and the active panel 2.47 mm,
    i.e. the bezel is asymmetric (13.5 / 18.4). The window was centred on the case;
    it is now centred on the panel and cut to the VIEWING area (111.5 x 63.0
    + 0.25/side), which was previously conflated with the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
    [C1_gpocket_1.5T.dxf, C1_gpocket_2T.dxf, C2_mouth_5T.dxf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]
2026-09-08 Correct Pi mounting and depth documentation; fix ORDER piece counts
    Documentation and preview only - no acrylic geometry changed (all 30 DXFs verified
    geometrically identical to the previous commit; verify_dxf.py ALL OK).
    * Pi mounting: retract the "the 5-inch needs a bracket" claim. Raspberry Pi's
    documentation says any SBC form-factor Pi mounts directly to the back of the
    Touch Display 2 on four corner stand-offs with the four supplied M2.5 screws.
    A full re-scan of the STEP confirms it contains no 58 x 49 pattern at all - it
    models the glass and frame body only, not the stand-offs - so the four
    103.7 x 51.0 rear bosses I had read as Pi mounting points are display assembly
    fea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
2026-09-11 Record the as-ordered straight-guide revision as v8; keep the v7 T-slot designs
    The acrylic that was actually sent for fabrication is not v7_clear_acrylzip. It is a
    later simplified revision, KETI_Acrylic_Order_REV4_StraightGuide_Transparent_2T_3T.dxf.
    Added as a new version; the v7 designs are untouched and kept as reference.
    Why the revision exists: the layered T-slot left a 1.0 mm acrylic lip running the whole
    length of the slot on the pocket layers. Laser-cuttable, but a long thin tongue and
    judged mechanically fragile. v8 replaces it with a plain straight open groove in every
    structural layer so the side wall keeps full section. The 5T sheet is gone; its depth is
    redistributed as 3T +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
    [C1_gpocket_2T.dxf, C2_guide_3T.dxf, C3_guide_2T.dxf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]
2026-09-11 Assembly guide for the fabricated parts, and a two-plate retrofit for Joy-Con retention
    The parts are back, so ASSEMBLY.md is rewritten as a build guide for what is physically
    in hand: how to tell the six plates apart, the cavity-offset trap when stacking L2-L5,
    seating the display glass in the L1 pocket with a gasket on the ledge, bolt order, and
    mounting the Pi on the display's own stand-offs with the display's own screws.
    It also states plainly what the built case does with a Joy-Con. The rail head is about
    10.1 x 2.4 mm behind a 7.1 x 0.7 neck; the ordered groove is a plain 11.0 x 3.4 rectangle,
    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
    [C1_gpocket_1.5T.dxf, C1_gpocket_2T.dxf, C2_guide_3T.dxf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]
2026-09-11 Add a GitHub Pages 3D assembly viewer; adopt the tape lip as the Joy-Con retention
    Six clear plates are hard to tell apart in the hand, so docs/ is a small interactive page:
    the stack rendered in 3D with an explode slider, click any plate to identify it, and a 2D
    silhouette of the selected plate to hold the real part against. It also carries the
    assembly steps and the Joy-Con tape numbers.
    make_site.py builds it. Each plate is exported as flat polygons - outer boundary plus
    holes - and extruded in the browser, so there are no model files, no loaders and no
    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
